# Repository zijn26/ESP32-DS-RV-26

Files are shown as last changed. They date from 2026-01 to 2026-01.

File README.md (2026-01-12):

Phần 1 . Hướng dẫn mở dự án kicad 

## 1️⃣ Giới thiệu

Project này được thiết kế bằng **KiCad** và bao gồm:

* **Schematic (sơ đồ nguyên lý)**
* **PCB Layout (mạch in nhiều lớp)**

Tài liệu này hướng dẫn cách mở và xem toàn bộ project bằng **KiCad** trên Windows, Linux hoặc macOS.

---

## 2️⃣ Phần mềm cần cài

Tải và cài đặt :

👉 **KiCad 7 hoặc KiCad 8 hoặc KiCad 9 **

Tải tại:
[https://www.kicad.org](https://www.kicad.org)

> ⚠ Khuyến nghị dùng Kicad 9, phiên bản mà project được tạo ra để tránh lỗi.

---

## 3️⃣ Cấu trúc thư mục project

Sau khi giải nén file ZIP, bạn sẽ thấy thư mục dạng:

```
MyProject/
├── esp32_module.kicad_pro
├── esp32_module.kicad_sch
├── esp32_module.kicad_pcb
├── MyFootprints.pretty
├── ul_myfootprinandsymbol
```

| File | Chức năng |
| --- | --- |
| `.kicad_pro` | File project chính  |
| `.kicad_sch` | Schematic |
| `.kicad_pcb` | PCB layout |
| `.pretty` | Footprint tùy chỉnh |
| `.kicad_sym` | Symbol tùy chỉnh |
| `ul_xxxxxxx` | File chứa các footprint và symbol tùy chỉnh |

---

## 4️⃣ Cách mở project trong KiCad

### Bước 1

Mở **KiCad**

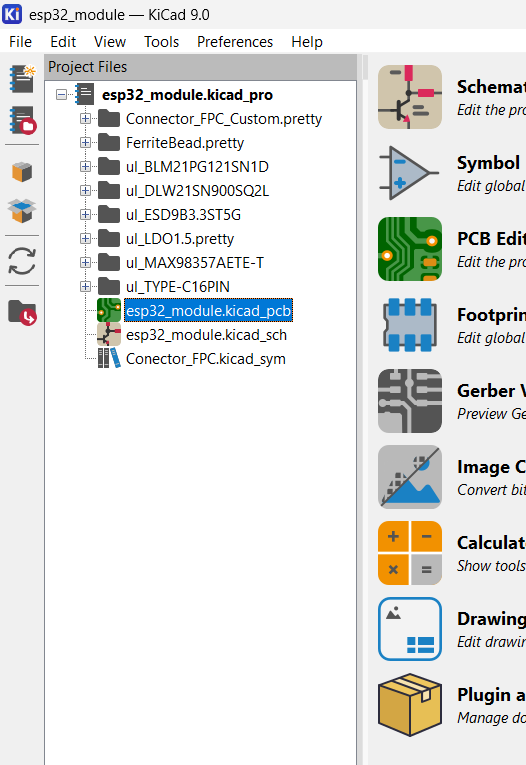
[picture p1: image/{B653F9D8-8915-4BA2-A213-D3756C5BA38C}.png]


---

### Bước 2

Nhấn **File → Open Project**

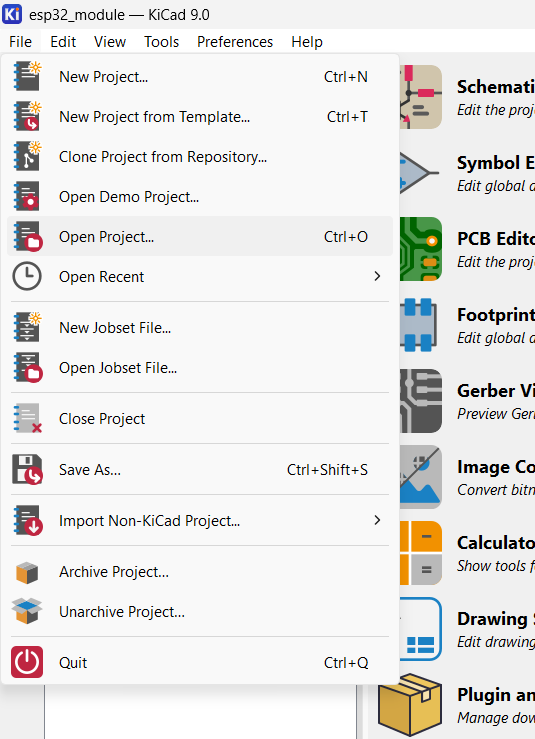
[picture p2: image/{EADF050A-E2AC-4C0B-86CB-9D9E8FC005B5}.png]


---

### Bước 3

Chọn file:

```
MyProject.kicad_pro
```

## 5️⃣ Mở Schematic (Sơ đồ nguyên lý)

Sau khi project mở:

Nhấn **Schematic Editor**

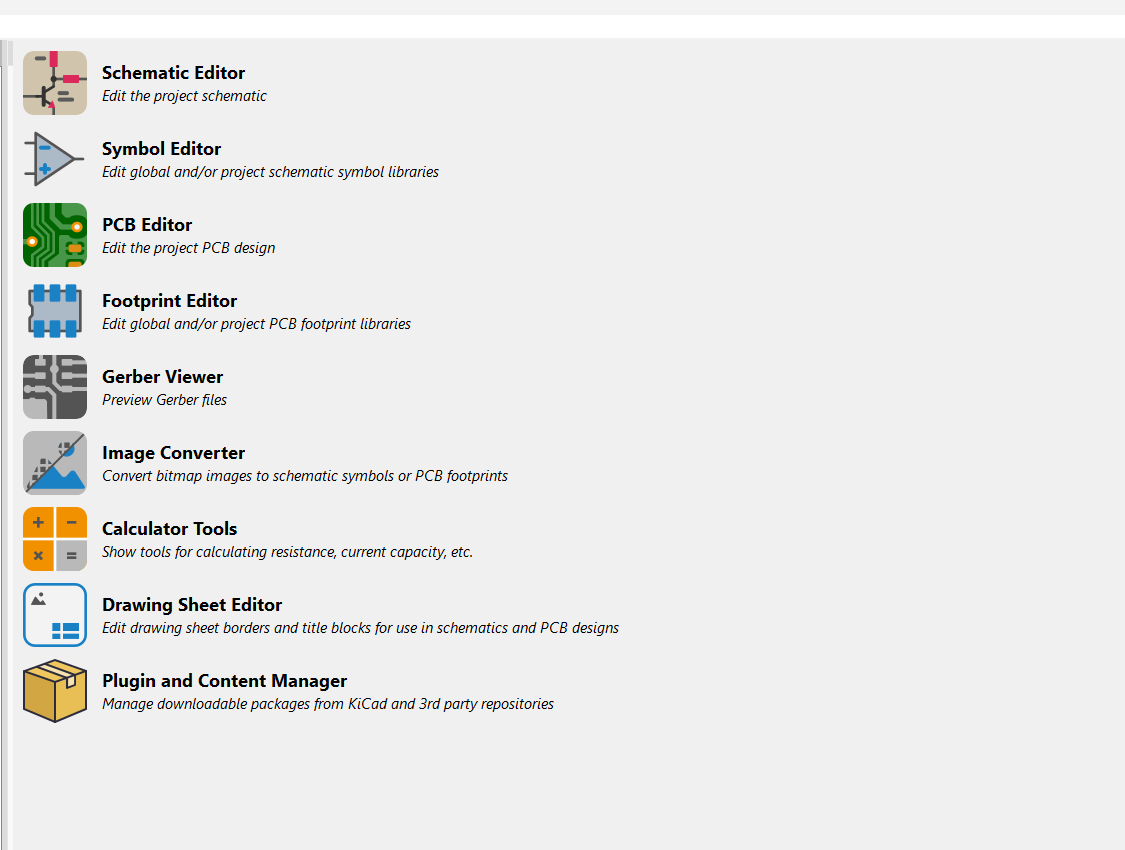
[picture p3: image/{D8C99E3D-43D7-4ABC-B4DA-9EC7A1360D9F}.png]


Sau đó sơ đồ nguyên lý sẽ xuất hiện.

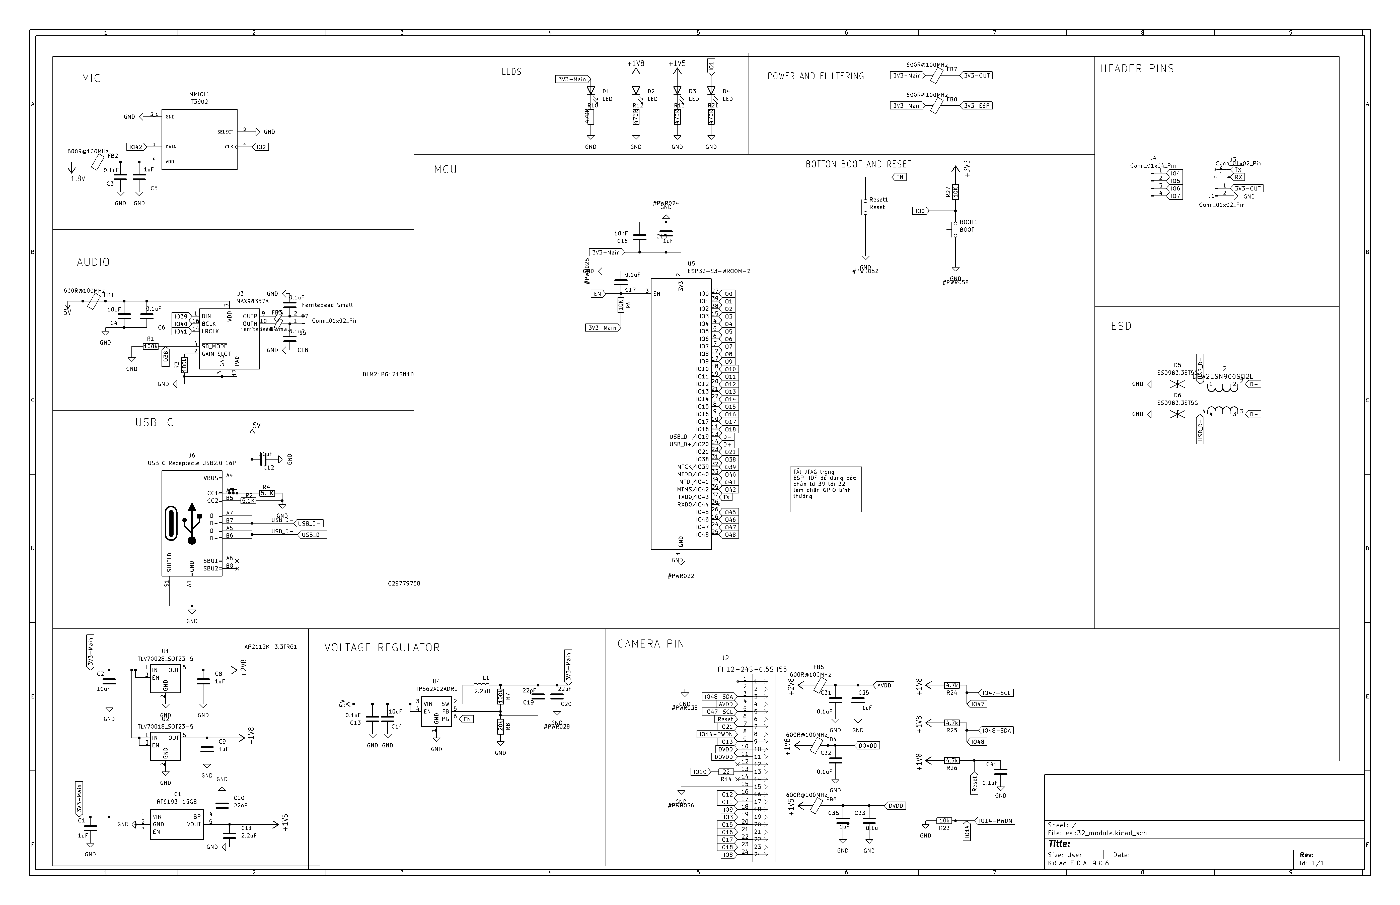
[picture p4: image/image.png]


---

## 6️⃣ Mở PCB Layout

Trong cửa sổ chính của KiCad:

Nhấn **PCB Editor**

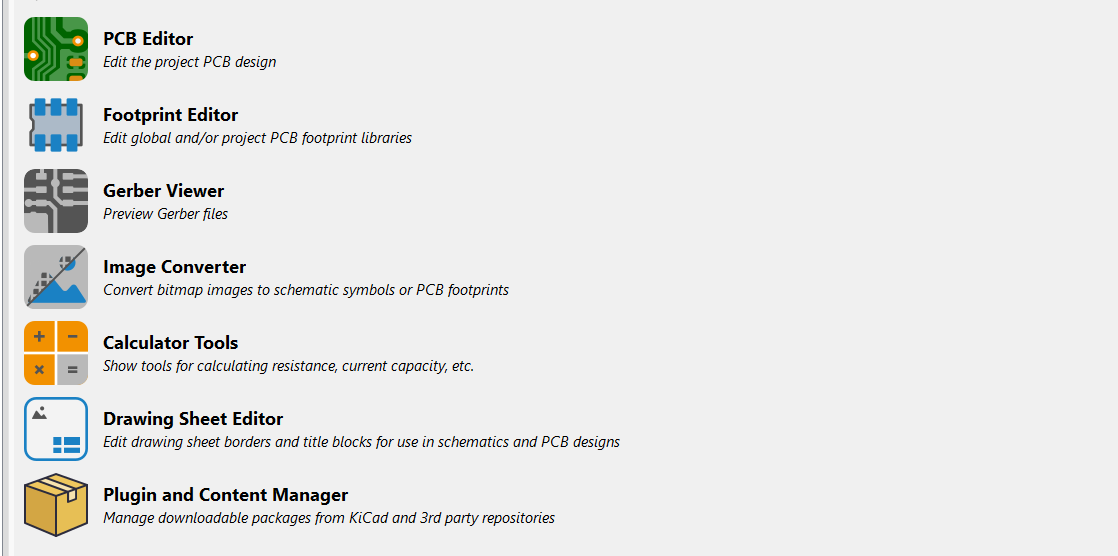
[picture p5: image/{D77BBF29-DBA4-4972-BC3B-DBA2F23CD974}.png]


PCB sẽ được mở ra với:

* Các lớp đồng (Top, Bottom, Inner layers)
* Via
* Plane
* Footprint

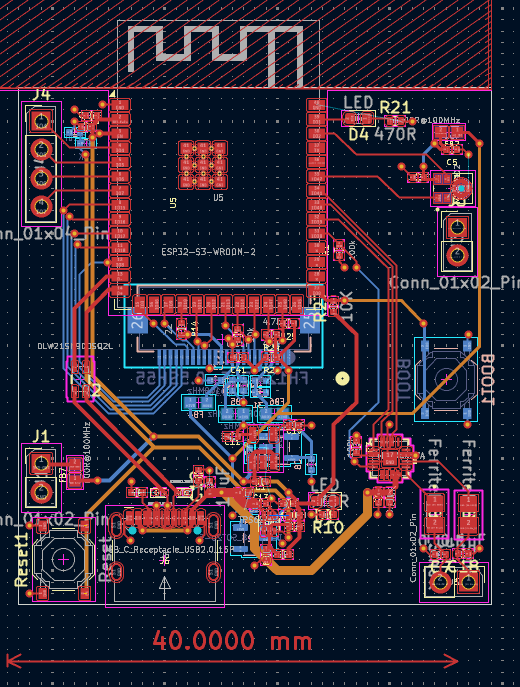
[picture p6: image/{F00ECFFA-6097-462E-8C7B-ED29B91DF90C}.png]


đang nằm **cùng thư mục với project**

Phần 2 : Thông tin về linh kiên sử dụng , giải thích về sơ đồ nguyên lý và mạch in

Thông tin về linh kiện sử dụng : 
Thầy hãy đọc file LINHKIENSUDUNG.md để biết thông tin chi tiết về linh kiện :
https://github.com/zijn26/ESP32-DS-RV-26/blob/main/LINHKIENSUDUNG.md
Thông tin về sơ đồ mạch và layout PCB , thày hãy đọc file GIAITHICH.md :
https://github.com/zijn26/ESP32-DS-RV-26/blob/main/GIAITHICH.md

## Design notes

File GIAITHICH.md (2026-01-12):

# 📋 Giải Thích Các Khối Trong Sơ Đồ Schematic và PCB Layout

---

## 🏗️ Tổng Quan Cấu Trúc PCB 4 Lớp

| Lớp | Tên | Chức năng |
|-----|-----|---|
| **Lớp 1** | Top | Lắp các linh kiện chính: Module ESP32-S3, Antenna, Mic, USB-C, ... |
| **Lớp 2** | GND Plane | Đổ full đồng làm mặt phẳng GND |
| **Lớp 3** | Power/Signal | Đi các đường nguồn (3V3, 5V, 1V8, 1V5) và tín hiệu (EN, ...) |
| **Lớp 4** | Bottom | Linh kiện phụ và linh kiện lớn: FPC Connector, LDO 2V8, LDO 1V8 |

---

## 1. 🔌 Khối USB-C (Nạp Code & Cấp Nguồn)

### Schematic

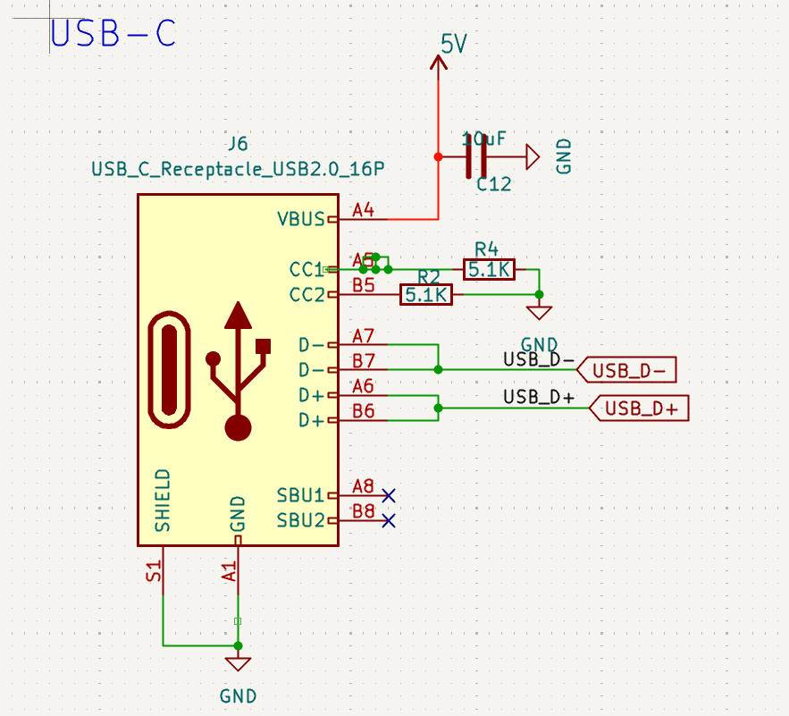
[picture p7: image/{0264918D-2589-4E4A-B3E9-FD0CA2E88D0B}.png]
USB-C Schematic


### Mô tả

Em sử dụng **USB-C 16P** với các kết nối:

- **Chân CC1 và CC2**: Dùng 2 điện trở **5.1kΩ** kéo xuống GND
- **Chân SHIELD**: Nối thẳng xuống GND

### Layout

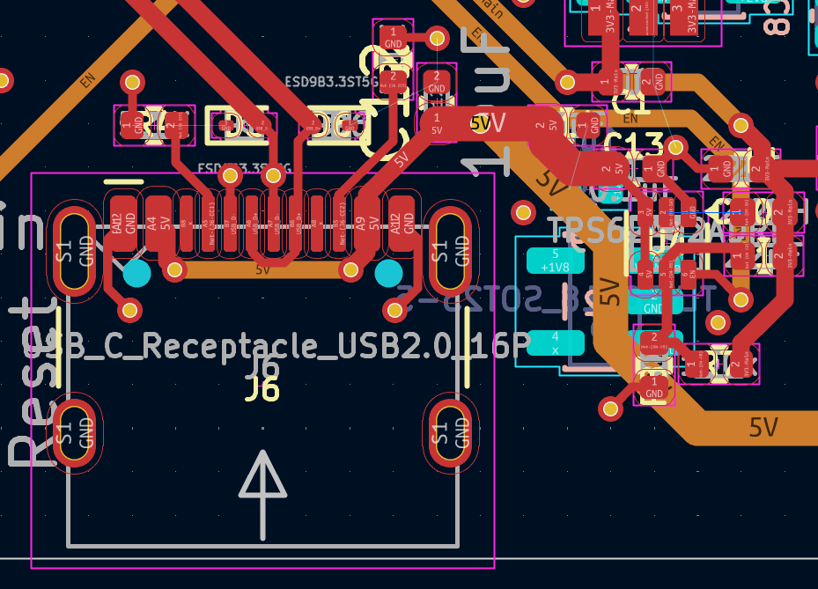
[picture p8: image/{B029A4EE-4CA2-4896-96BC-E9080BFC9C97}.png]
USB-C Layout


#### Chi tiết thiết kế:

- Nối 2 chân **B7** và **A7** lại với nhau thông qua **via Through**
- Dây **D-** và **D+** đi qua:
  1. **ESD9B3.3ST5G** (ESD Protection Diode)
  2. **DLW21SN900SQ2L** (Common Mode Choke) để lọc nhiễu
  3. Cuối cùng đi tới ESP32-S3

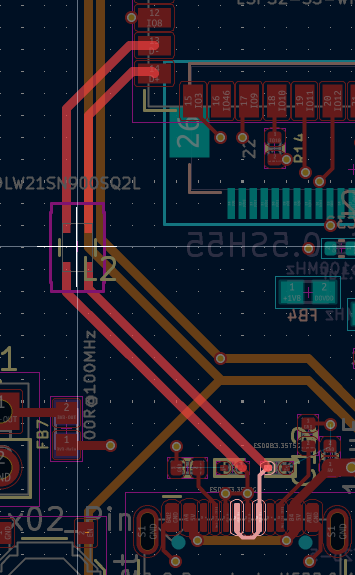
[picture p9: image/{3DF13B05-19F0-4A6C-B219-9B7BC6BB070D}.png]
USB Data Lines


- 2 pad **5V** được nối lại với nhau thông qua via through, đi qua tụ bulk **10µF (C12)** trước khi đi tới khối Buck

> **❓ Câu hỏi:**
> 1. Cách nối B7, A7 lại với nhau thông qua via Through có đúng không ạ ?
> 2. Cách dùng ESD protection diode ESD9B3.3ST5G có đúng không ạ ?
> 3. Cách đi dây đã ổn chưa ạ ?

---

## 2. ⚡ Khối Buck Converter (5V → 3V3)

### Schematic & Layout

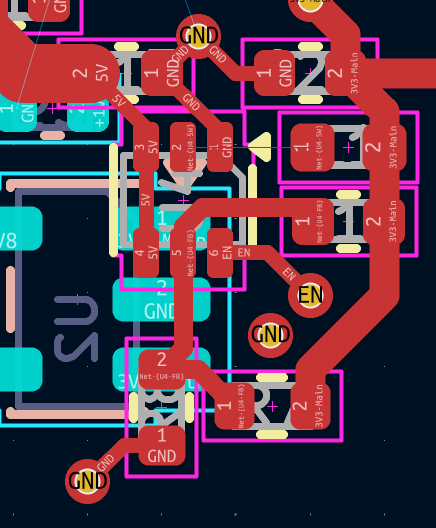
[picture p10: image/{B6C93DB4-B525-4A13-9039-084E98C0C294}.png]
Buck Schematic

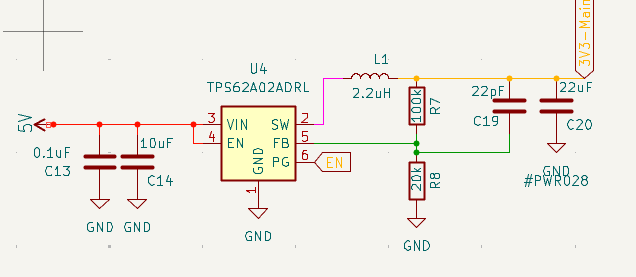
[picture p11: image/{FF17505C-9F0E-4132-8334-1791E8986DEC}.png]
Buck Layout


### Mô tả

- Sử dụng **2 tụ decoupling** ngay sát chân 5V để đón dòng vào Buck
- Đầu ra sử dụng **mạch chia áp** để nhận được 3V3

### LDO 1V8 (Lớp 4 - Bottom)

Ở bên dưới Buck (lớp 4), đặt **LDO 1V8** để:
- Đón dòng 3V3 và chuyển thành 1V8
- Cấp nguồn cho chân **DOVDD** của FPC Connector

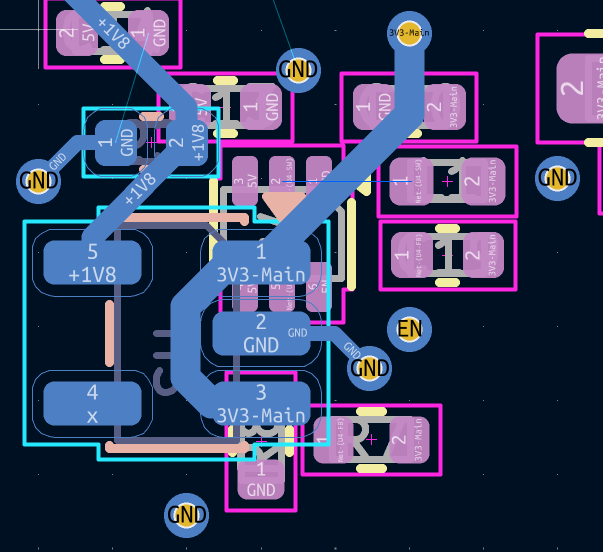
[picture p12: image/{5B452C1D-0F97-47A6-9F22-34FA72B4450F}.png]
LDO 1V8 - 1

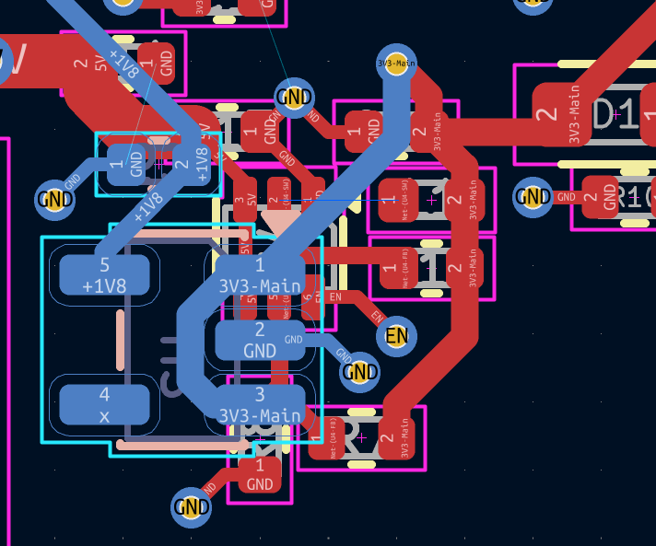
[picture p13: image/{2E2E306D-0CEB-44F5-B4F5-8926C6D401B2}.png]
LDO 1V8 - 2

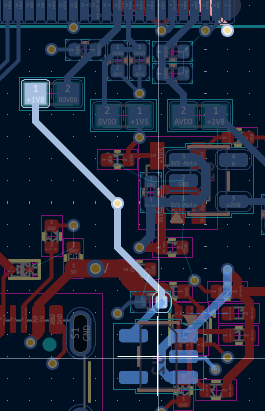
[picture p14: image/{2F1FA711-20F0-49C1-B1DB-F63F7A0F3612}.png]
LDO 1V8 - 3


### Điều khiển Power Good (PG)

Sử dụng chân **PG** của Buck để điều khiển chân **EN** của ESP32-S3:
- Mục đích: Khi dòng 3V3 ổn định thì module mới khởi động

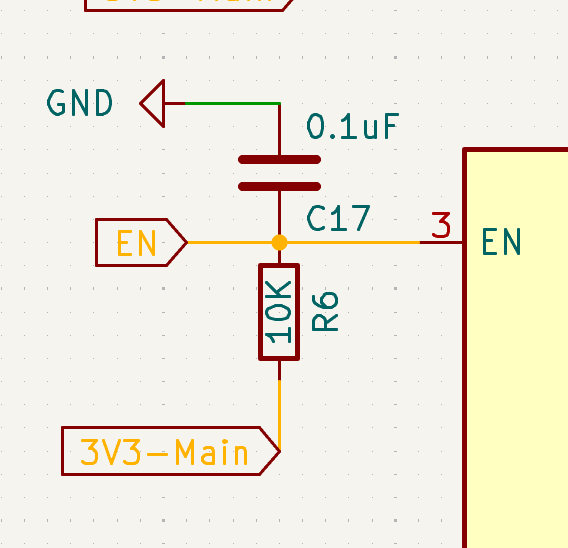
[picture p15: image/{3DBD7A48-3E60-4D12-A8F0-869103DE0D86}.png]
PG Control - 1

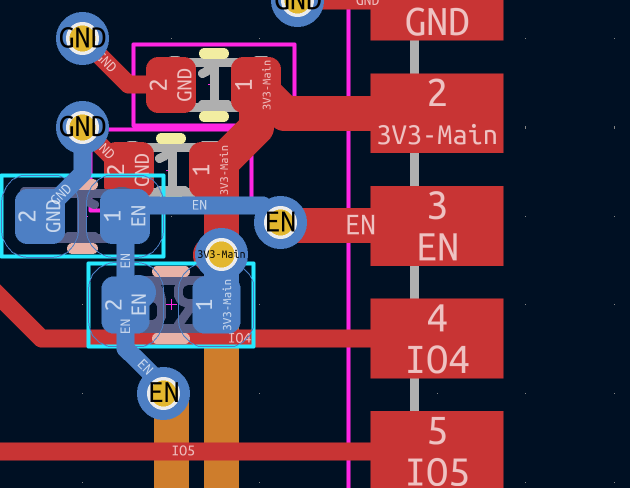
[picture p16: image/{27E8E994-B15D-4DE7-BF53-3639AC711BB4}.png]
PG Control - 2


> *Mạch màu xanh: Chân PG kết nối vào chân EN của ESP32 để khởi động*

### Cấp nguồn cho ESP32-S3

- Cấp nguồn **3V3** từ Buck
- Sử dụng **2 tụ decoupling** sát chân 3V3 của module

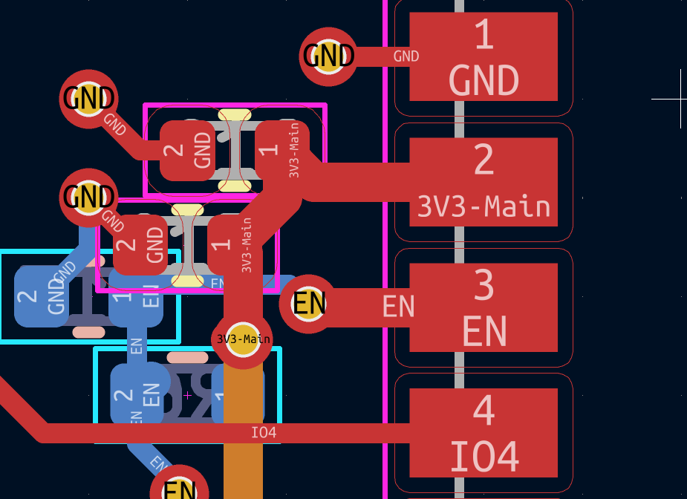
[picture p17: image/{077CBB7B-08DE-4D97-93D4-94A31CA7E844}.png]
ESP32 Power


---

## 3. 🔋 Khối LDO

### Bố trí

| LDO | Vị trí | Chức năng |
|-----|---|---|
| **3V3 → 1V5** | Lớp 1 (Top) | Cấp nguồn DVDD cho Camera |
| **3V3 → 2V8** | Lớp 4 (Bottom) | Cấp nguồn AVDD cho Camera |

> Cả 2 khối LDO được đặt **gần FPC Connector** để giảm độ dài đường dây nguồn.

### Schematic & Layout

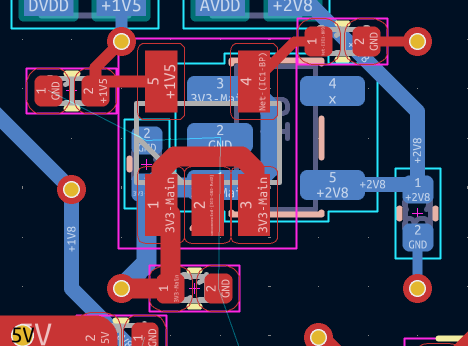
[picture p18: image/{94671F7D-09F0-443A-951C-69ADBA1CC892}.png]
LDO Overview

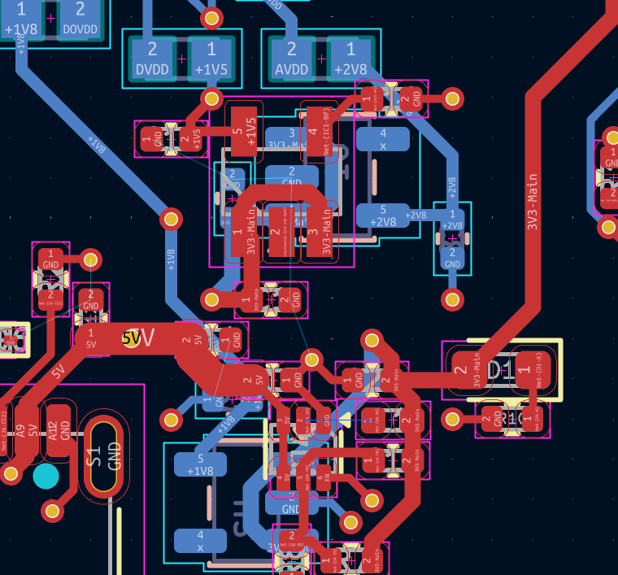
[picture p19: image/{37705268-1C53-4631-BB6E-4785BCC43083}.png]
LDO Layout 1

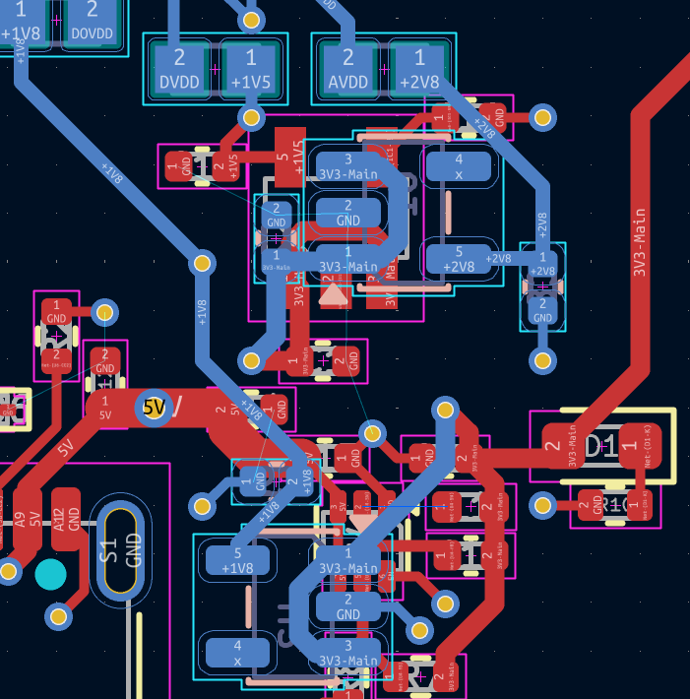
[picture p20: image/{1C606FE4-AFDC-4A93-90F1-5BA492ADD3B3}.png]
LDO Layout 2

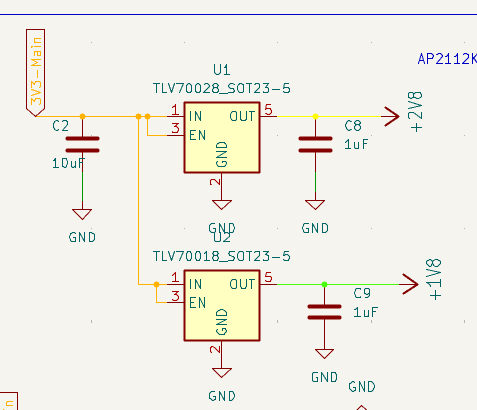
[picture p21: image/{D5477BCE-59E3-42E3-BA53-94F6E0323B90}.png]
LDO Layout 3

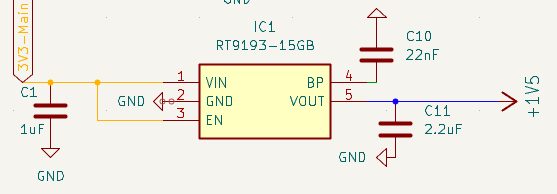
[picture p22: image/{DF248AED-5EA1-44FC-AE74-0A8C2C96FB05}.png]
LDO Layout 4


---

## 4. 📷 Khối FPC Connector (Camera)

### Schematic

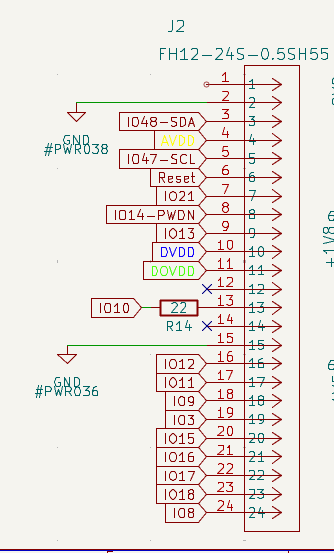
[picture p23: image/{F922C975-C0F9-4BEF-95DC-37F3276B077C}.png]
FPC Schematic 1

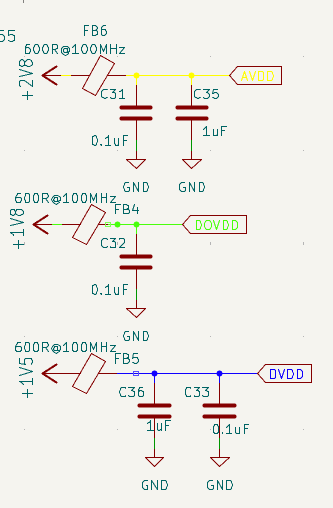
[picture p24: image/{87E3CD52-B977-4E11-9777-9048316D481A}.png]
FPC Schematic 2

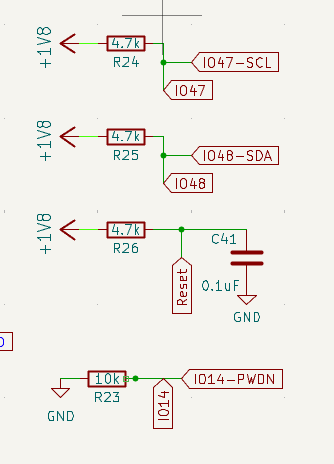
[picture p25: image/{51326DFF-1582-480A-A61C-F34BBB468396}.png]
FPC Schematic 3


### Mô tả

Khối FPC Connector kết nối **camera OV2640** với ESP32-S3:
- Đặt **gần ESP32-S3** để giảm nhiễu và giảm độ dài dây kết nối

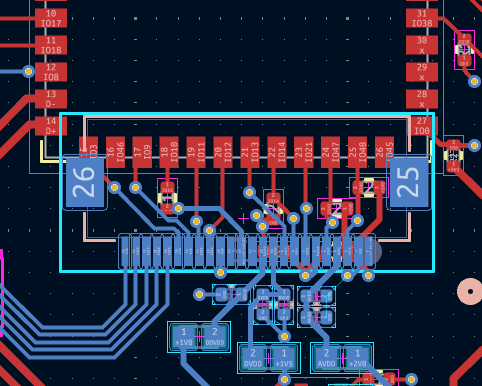
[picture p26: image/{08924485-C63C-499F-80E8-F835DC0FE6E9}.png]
FPC Layout


### Thiết kế chi tiết

| Thành phần | Thiết kế |
|---|---|
| **Ferrite Bead** | Giảm nhiễu cho các chân nguồn của FPC |
| **AVDD (2V8)** | Ferrite Bead BEADC1608X95N 600R@100MHz + 2 tụ decoupling (0.1µF, 1µF) |
| **DOVDD (1V8)** | Tương tự AVDD |
| **DVDD (1V5)** | Tương tự AVDD |
| **MCLK** | GPIO 10 của ESP32-S3 cấp clock |
| **SDA/SCL** | Mạch pull-up kết hợp GPIO 47, GPIO 48 |
| **RESET** | Mạch RC để reset sạch, ổn định |
| **PWDN** | Mạch pull-down |

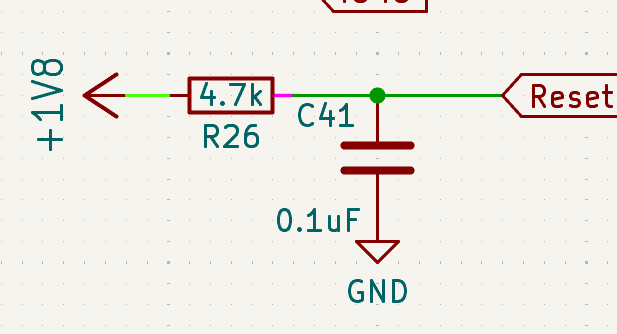
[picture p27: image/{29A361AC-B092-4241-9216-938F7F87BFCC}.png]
Reset Circuit

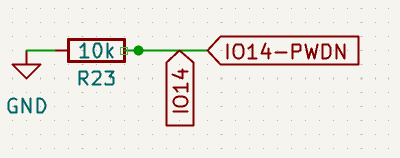
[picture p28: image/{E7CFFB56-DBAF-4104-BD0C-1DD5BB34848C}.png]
PWDN Circuit


---

## 5. 🔊 Khối Audio Amplifier (AMP)

### Bố trí

- Đặt **gần mép board**, cách xa LDO và FPC để tránh nhiễu
- 3 dây **DIN, BCLK, LRCLK** đi song song, thẳng

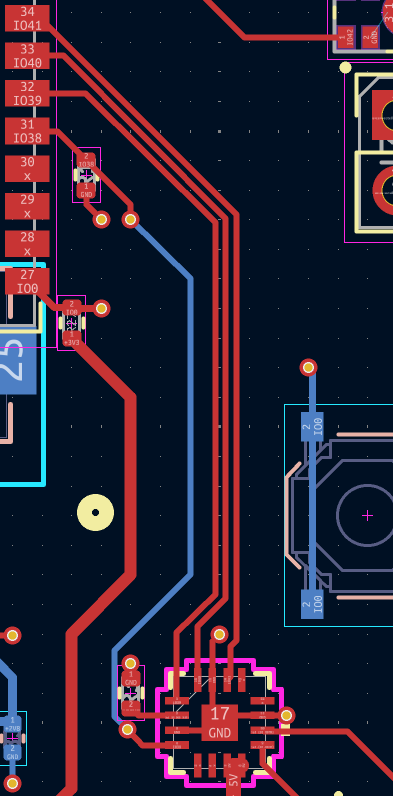
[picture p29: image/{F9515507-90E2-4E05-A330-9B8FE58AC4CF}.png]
AMP Layout


### Thiết kế chi tiết

| Chân | Thiết kế |
|---|---|
| **SD_MODE** | Mạch pull-down + GPIO38 điều khiển |
| **VDD** | Ferrite Bead giảm nhiễu + 2 tụ decoupling |
| **OUTP/OUTN** | 2 tụ trên đường dây tín hiệu xuất ra → Header Pin → Loa |

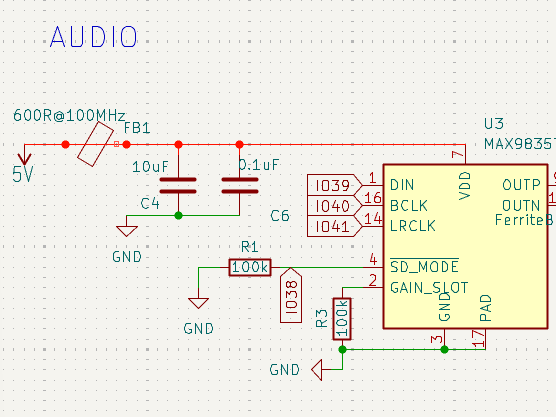
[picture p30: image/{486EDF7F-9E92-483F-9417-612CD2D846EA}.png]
AMP VDD

AMP Schematic
AMP Output

> ⚠️ *Em đã sửa lại mạch: Xóa các Ferrite Bead sau chân OUTP/OUTN, chỉ dùng tụ*

AMP Output Updated

> **❓ Câu hỏi:**
> Với các chân OUTP và OUTN nếu chỉ dùng tụ không thì âm thanh đầu ra có bị dè hay nhiễu không? Nếu có thì em nên khắc phục như thế nào?

---

## 6. 🎤 Khối Mic PDM

### Bố trí

- Đặt **tránh xa LDO, Buck, FPC Connector và AMP** để tránh nhiễu
- Đặt **gần ESP32-S3** để dây DATA và CLK đi ngắn nhất, thẳng nhất

### Thiết kế chi tiết

| Chân | Thiết kế |
|---|---|
| **VDD** | Ferrite Bead giảm nhiễu + 2 tụ decoupling |
| **SELECT** | Nối thẳng xuống GND |
| **Nguồn** | Cấp 1V8 cho Mic |

Mic Schematic
Mic Layout
Mic SELECT
Mic Power

---

## 7. 📐 Tổng Quan Layout PCB

### Lớp Top (Lớp 1)

PCB Top

### Lớp Bottom (Lớp 4)

PCB Bottom

### Các thành phần khác

| Thành phần | Layout |
|---|---|
| **Nút Reset** | Reset Button |
| **Nút Boot** | Boot Button |

### Routing dây Data FPC

FPC Data Lines

> **Lưu ý:** Các dây data của FPC đi ở **Lớp 4**, còn 2 dây D- và D+ đi ở **Lớp 1**

### Hình ảnh tổng quan

Full PCB

---

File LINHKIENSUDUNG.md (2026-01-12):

# 📒 Danh Sách & Thông Tin Linh Kiện

---

## 🧩 1. Giới Thiệu

Tài liệu này mô tả **toàn bộ các linh kiện** được sử dụng trong project PCB, bao gồm:

- Tên linh kiện & chức năng
- Thông số kỹ thuật chi tiết
- Hình ảnh minh họa
- Link tham khảo trên JLCPCB

---

## 📋 2. Danh Sách Linh Kiện Tổng Quan

| STT | Tên Linh Kiện | Mã JLCPCB |
|:---:|---|---|
| 1 | ESP32-S3-WROOM Module N16R8 | C2913202 |
| 2 | FPC Connector 24-pin (Camera) | C202112 |
| 3 | Buck Converter TPS62A02 | C5820994 |
| 4 | LDO TLV70028 (2.8V) | C5820994 |
| 5 | LDO RT9193-15GB (1.5V) | C2972229 |
| 6 | PDM Microphone MMICT390200012 | C3171752 |
| 7 | Audio Amplifier MAX98357AETE+T | C910544 |
| 8 | ESD Protection ESD9B3.3ST5G | C96512 |
| 9 | Common Mode Choke DLW21SN900SQ2L | C97856 |
| 10 | USB Type-C 16P | C393939 |

---

## 🧰 3. Chi Tiết Linh Kiện

---

### 🧠 1. ESP32-S3-WROOM Module

| Thông số | Giá trị |
|---|---|
| **Chức năng** | Vi điều khiển chính, Wi-Fi, Bluetooth, xử lý camera, audio |
| **Điện áp** | 3.3V |
| **CPU** | Xtensa dual-core 32-bit LX7 @ 240 MHz |
| **SRAM** | 512 kB nội bộ |
| **Flash** | 16 MB (SPI) |
| **PSRAM** | 8 MB ngoài |
| **GPIO** | 45 chân đa năng (ADC, SPI, I2C, UART, PWM, USB OTG) |

ESP32-S3 Module

🔗 **Link JLCPCB:** [C2913202](https://jlcpcb.com/partdetail/3198300-ESP32_S3_WROOM_1N16R8/C2913202)

---

### 📷 2. FPC Connector 24-pin (Camera)

| Thông số | Giá trị |
|---|---|
| **Chức năng** | Kết nối camera OV2640 / OV5640 / OV3660 |
| **Pitch** | 0.5mm |
| **Tương thích** | OV2640 (2MP), OV5640 (5MP), OV3660 (3MP) |

FPC Connector - 1
FPC Connector - 2

#### Các chân chính:

| Chân | Chức năng |
|---|---|
| XCLK | Clock |
| PCLK | Pixel clock |
| HREF | Horizontal reference |
| VSYNC | Vertical sync |
| D0-D7 | Data bits |
| SDA/SCL | I2C config |

🔗 **Link JLCPCB:** [C202112](https://jlcpcb.com/partdetail/HRS_Hirose-FH12_24S_0_5SH_55/C202112)

---

### ⚡ 3. Buck Converter TPS62A02

| Thông số | Giá trị |
|---|---|
| **Chức năng** | Hạ áp 5V → 3.3V cho toàn hệ thống |
| **Điện áp vào** | 2.5V - 5.5V |
| **Điện áp ra** | 0.6V - VIN (điều chỉnh được) |
| **Dòng tối đa** | 2A |
| **Tần số chuyển mạch** | 2.4MHz |
| **Quiescent current** | < 23µA |
| **Package** | SOT-563 (DRL-6) |

Buck TPS62A02 - 1
Buck TPS62A02 - 2

#### Tính năng bảo vệ:

- ✅ Soft-start tích hợp
- ✅ Bảo vệ ngắn mạch (HICCUP mode)
- ✅ Xả output chủ động
- ✅ Thermal shutdown
- ✅ Độ chính xác feedback 1% (0-125°C)
- ✅ Hỗ trợ 100% duty cycle cho dropout thấp

🔗 **Link JLCPCB:** [C5820994](https://jlcpcb.com/parts/componentSearch?searchTxt=C5820994)

---

### 🔋 4. LDO TLV70028 (2.8V)

| Thông số | Giá trị |
|---|---|
| **Chức năng** | LDO 200mA, đầu ra cố định 2.8V cho Camera |
| **Điện áp vào** | 2V - 5.5V |
| **Dropout** | 30mV @ 200mA |
| **Quiescent current** | ~3.9µA |
| **PSRR** | 70dB @ 10kHz |
| **Package** | SOT-23-5 (DBV) |
| **Kích thước** | 2.9 x 1.6mm |

LDO TLV70028 - 1
LDO TLV70028 - 2

#### Pinout:

| Pin | Chức năng |
|-----|---|
| 1 | IN |
| 2 | GND |
| 3 | EN |
| 4 | NC |
| 5 | OUT |

> **Ứng dụng:** LDO hậu Buck TPS62A02 cho rail 2.8V ổn định, cấp nguồn AVDD cho Camera (dòng < 200mA)

🔗 **Link JLCPCB:** [C5820994](https://jlcpcb.com/partdetail/TexasInstruments-TPS62A02ADRLR/C5820994)

---

### 🔋 5. LDO RT9193-15GB (1.5V)

| Thông số | Giá trị |
|---|---|
| **Chức năng** | LDO 300mA, đầu ra cố định 1.5V cho Camera |
| **Điện áp vào** | 2.5V - 5.5V |
| **Dropout** | 220mV @ 300mA |
| **Quiescent current** | 90-130µA |
| **PSRR** | 70dB (100Hz) - 50dB (10kHz) |
| **Noise** | < 100µVRMS |
| **Package** | SOT-23-5 (GB/Z00) |

LDO RT9193 - 1
LDO RT9193 - 2
LDO RT9193 - 3

#### Pinout:

| Pin | Chức năng |
|-----|---|
| 1 | IN |
| 2 | GND |
| 3 | EN/SHDN |
| 4 | BYP (noise reduction) |
| 5 | OUT |

#### Tính năng:

- ✅ Current limit tích hợp
- ✅ Thermal shutdown (165°C)
- ✅ Shutdown current < 0.01µA
- ✅ Start-up nhanh < 50µs
- ✅ Chỉ cần C_OUT 1µF

> **Ứng dụng:** LDO hậu Buck TPS62A02 cho rail 1.5V ổn định, cấp nguồn DVDD cho Camera

🔗 **Link JLCPCB:** [C2972229](https://jlcpcb.com/partdetail/RichtekTech-RT919315GB/C2972229)

---

### 🎤 6. PDM Microphone MMICT390200012

| Thông số | Giá trị |
|---|---|
| **Chức năng** | Thu âm thanh dạng PDM |
| **Điện áp** | 1.65V - 3.63V |
| **Dòng tiêu thụ** | 650µA |
| **Độ nhạy** | -32dB ±1dB @ 94dB SPL |
| **SNR** | 64dB |
| **SPL tối đa** | 120dB |
| **Tần số** | 36Hz - 20kHz |
| **Hướng thu** | Omnidirectional, bottom port |
| **EIN** | 30dBA (low noise) |

PDM Mic - 1
PDM Mic - 2

#### Package:

| Thông số | Giá trị |
|---|---|
| Kích thước | 3.50 x 2.65 x 0.98mm |
| Lắp đặt | Surface mount, 5 chân |
| Nhiệt độ | -40°C đến 85°C |
| Chuẩn | RoHS compliant |

> **Ứng dụng:** Interface PDM tích hợp với ESP32-S3 I2S/PDM RX cho voice recognition hoặc audio streaming kết hợp camera OV2640

🔗 **Link JLCPCB:** [C3171752](https://jlcpcb.com/partdetail/TDKInvenSense-MMICT390200012/C3171752)

---

### ⚡ 7. ESD Protection Diode ESD9B3.3ST5G

| Thông số | Giá trị |
|---|---|
| **Chức năng** | Bảo vệ ESD hai chiều cho đường tín hiệu 3.3V |
| **Breakdown voltage** | 7V max |
| **Clamping voltage** | 11.5V |
| **Capacitance** | 15pF @ 1MHz |
| **Công suất** | 0.3W |
| **Leakage current** | < 50nA |
| **Nhiệt độ** | -55°C đến +150°C (TJ) |
| **Package** | SOD-923 (0.8 x 0.6 x 0.37mm) |

ESD Diode - 1
ESD Diode - 2

#### Ứng dụng:

- USB-C16PIN (VBUS, D+, D-, CC)
- GPIO ESP32-S3
- I2S audio lines

> **Lắp đặt:** Đặt parallel với đường tín hiệu cần bảo vệ. Không cần hướng pin cụ thể (bidirectional).

🔗 **Link JLCPCB:** [C96512](https://jlcpcb.com/partdetail/onsemi-ESD9B33ST5G/C96512)

---

### � 8. Common Mode Choke DLW21SN900SQ2L

| Thông số | Giá trị |
|---|---|
| **Chức năng** | Bộ lọc nhiễu chế độ chung (Common Mode Filter) |
| **Trở kháng** | 90Ω @ 100MHz (±25%) |
| **Dòng định mức** | 330mA |
| **Điện áp định mức** | 50V DC (chịu được 125V) |
| **Điện trở DC** | max 0.35Ω mỗi đường |
| **Cách điện** | min 10MΩ |
| **Package** | SMD 0805 (2.0 x 1.2 x 1.2mm) |

CMC - 1
CMC - 2

#### Cấu trúc:

- 4 chân SMD (2 line pairs)
- Cấu hình 1 mạch (line 1-2 và line 3-4)
- High coupling coefficient giữ tín hiệu differential nguyên vẹn

> **Ứng dụng:** USB, I2S, high-speed data lines

🔗 **Link JLCPCB:** [C97856](https://jlcpcb.com/partdetail/MurataElectronics-DLW21SN900SQ2L/C97856)

---

### 🔊 9. Audio Amplifier MAX98357AETE+T

| Thông số | Giá trị |
|---|---|
| **Chức năng** | Khuếch đại âm thanh Class D cho loa |
| **Điện áp** | 2.5V - 5.5V |
| **Công suất** | 3.2W @ 4Ω/5V (THD+N 10%) |
| **Hiệu suất** | 92% |
| **Noise floor** | 22.8μVRMS |
| **THD+N** | 0.013% @ 1kHz/1W |
| **PSRR** | 77dB @ 1kHz |
| **Quiescent** | 2.4mA |
| **Sample rate** | 8-96kHz |
| **Package** | TQFN-16 (3x3mm) |

Audio AMP

#### Tính năng:

- ✅ Không cần MCLK
- ✅ Gain có thể chọn: 6/12/15dB
- ✅ Filterless output (giảm EMI)
- ✅ Shielded GND riêng cho output stage

#### Pinout chính:

| Chân | Chức năng |
|---|---|
| VDD/GND | Nguồn |
| BCLK/LRCLK/DIN | I2S input |
| GAIN_SLOT | Chọn gain |
| OUTP/OUTN | Speaker differential output |
| SD | Shutdown control |

> **Ứng dụng:** Tối ưu cho ESP32-S3 với I2S output

🔗 **Link JLCPCB:** [C910544](https://jlcpcb.com/partdetail/978950-MAX98357AETET/C910544)

---

### 🔌 10. USB Type-C 16P

| Thông số | Giá trị |
|---|---|
| **Chức năng** | Cấp nguồn + giao tiếp USB |
| **Điện áp định mức** | 30V |
| **Dòng tối đa** | 3A mỗi chân |
| **Nhiệt độ hoạt động** | -40°C đến +85°C |
| **Độ bền** | 10,000 chu kỳ cắm/rút |
| **Kháng trở tiếp xúc** | ≤ 20mΩ |
| **Cách điện** | > 100MΩ |
| **Lắp ráp** | Surface mount, right angle |

USB-C - 1
USB-C - 2

#### Kích thước:

| Thông số | Giá trị |
|---|---|
| Kích thước | ~8.94 x 7.35 x 3.16mm |
| Kiểu | Horizontal SMD |
| Pitch | Tiêu chuẩn Type-C |
| Solder heat resistance | 260°C/3s |

> **Lưu ý:** Tích hợp positioning peg giảm misalignment khi reflow. Đạt chuẩn RoHS.

🔗 **Link JLCPCB:** [C393939](https://jlcpcb.com/partdetail/SHOUHAN-TYPEC16PIN/C393939)

---

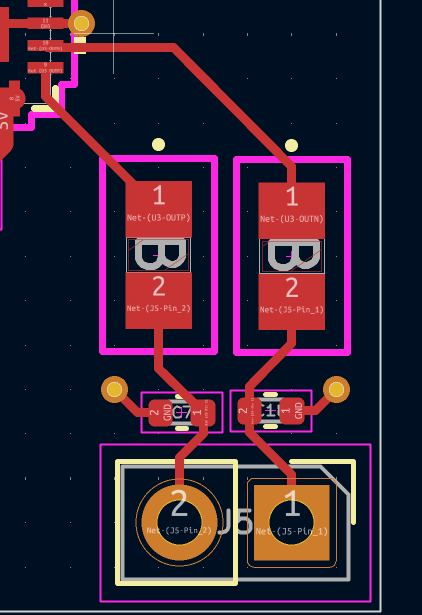
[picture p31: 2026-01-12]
image/{BC1A247C-B683-4670-9397-5359815A4F0C}.png

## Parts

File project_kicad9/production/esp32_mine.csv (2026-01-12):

Reference | Qty | Value | DNP | Footprint | Datasheet | MNF PART NUMBER | Description | LCSC
BOOT1 | 1 | BOOT |  | Button_Switch_SMD:SW_Push_1P1T_XKB_TS-1187A | ~ | C318884 | Push button switch, generic, two pins | C318884
C1 | 1 | 1uF |  | Capacitor_SMD:C_0402_1005Metric | ~ | C52923 |  | C52923
C2 | 1 | 10uF |  | Capacitor_SMD:C_0402_1005Metric | ~ | C15525 |  | C15525
C3 | 1 | 0.1uF |  | Capacitor_SMD:C_0402_1005Metric | ~ | C1525 |  | C1525
C4 | 1 | 10uF |  | Capacitor_SMD:C_0402_1005Metric | ~ | C1525 |  | C1525
C5 | 1 | 1uF |  | Capacitor_SMD:C_0402_1005Metric | ~ | C15525 |  | C15525
C6 | 1 | 0.1uF |  | Capacitor_SMD:C_0402_1005Metric | ~ | C15525 |  | C15525
C7 | 1 | 0.1uF |  | Capacitor_SMD:C_0402_1005Metric | ~ | C15525 |  | C15525
C8 | 1 | 1uF |  | Capacitor_SMD:C_0402_1005Metric | ~ | C52923 |  | C52923
C9 | 1 | 1uF |  | Capacitor_SMD:C_0402_1005Metric | ~ | C52923 |  | C52923
C10 | 1 | 22nF |  | Capacitor_SMD:C_0402_1005Metric | ~ | C15525 |  | C15525
C11 | 1 | 2.2uF |  | Capacitor_SMD:C_0402_1005Metric | ~ | C107369 |  | C107369
C12 | 1 | 10uF |  | Capacitor_SMD:C_0402_1005Metric | ~ | C15525 |  | C15525
C13 | 1 | 0.1uF |  | Capacitor_SMD:C_0402_1005Metric | ~ | C1525 |  | C1525
C14 | 1 | 10uF |  | Capacitor_SMD:C_0402_1005Metric | ~ | C15525 |  | C15525
C15 | 1 | 1uF |  | Capacitor_SMD:C_0402_1005Metric | ~ | C52923 |  | C52923
C16 | 1 | 10nF |  | Capacitor_SMD:C_0402_1005Metric | ~ | C15195 |  | C15195
C17 | 1 | 0.1uF |  | Capacitor_SMD:C_0402_1005Metric | ~ | C1525 |  | C1525
C18 | 1 | 0.1uF |  | Capacitor_SMD:C_0402_1005Metric | ~ | C15525 |  | C15525
C19 | 1 | 22pF |  | Capacitor_SMD:C_0402_1005Metric | ~ | C70464 |  | C70464
C20 | 1 | 22uF |  | Capacitor_SMD:C_0402_1005Metric | ~ | C105226 |  | C105226
C31 | 1 | 0.1uF |  | Capacitor_SMD:C_0402_1005Metric | ~ | C1525 |  | C1525
C32 | 1 | 0.1uF |  | Capacitor_SMD:C_0402_1005Metric | ~ | C1525 |  | C1525
C33 | 1 | 0.1uF |  | Capacitor_SMD:C_0402_1005Metric | ~ | C1525 |  | C1525
C35 | 1 | 1uF |  | Capacitor_SMD:C_0402_1005Metric | ~ | C52923 |  | C52923
C36 | 1 | 1uF |  | Capacitor_SMD:C_0402_1005Metric | ~ | C52923 |  | C52923
C41 | 1 | 0.1uF |  | Capacitor_SMD:C_0402_1005Metric | ~ | C1525 |  | C1525
D1 | 1 | LED |  | LED_SMD:LED_0603_1608Metric | ~ | C2286 |  | C2286
D2 | 1 | LED |  | LED_SMD:LED_0603_1608Metric | ~ | C2286 |  | C2286
D3 | 1 | LED |  | LED_SMD:LED_0603_1608Metric | ~ | C2286 |  | C2286
D4 | 1 | LED |  | LED_SMD:LED_0603_1608Metric | ~ | C2286 |  | C2286
D5 | 1 | ESD9B3.3ST5G |  | Diode_SMD:D_SOD-923 | https://www.onsemi.com/pub/Collateral/ESD9B-D.PDF |  | ESD protection diode, 3.3Vrwm, SOD-923
D6 | 1 | ESD9B3.3ST5G |  | Diode_SMD:D_SOD-923 | https://www.onsemi.com/pub/Collateral/ESD9B-D.PDF |  | ESD protection diode, 3.3Vrwm, SOD-923
FB1 | 1 | 600R@100MHz |  | FerriteBead:BEADC1608X95N | ~ | C19330 | Ferrite bead
FB2 | 1 | 600R@100MHz |  | FerriteBead:BEADC1608X95N | ~ | C19330 | Ferrite bead
FB3 | 1 | FerriteBead_Small |  | FerriteBead:ul_BLM21PG121SN1D | ~ |  | Ferrite bead, small symbol
FB4 | 1 | 600R@100MHz |  | FerriteBead:BEADC1608X95N | ~ | C19330 | Ferrite bead
FB5 | 1 | 600R@100MHz |  | FerriteBead:BEADC1608X95N | ~ | C19330 | Ferrite bead
FB6 | 1 | 600R@100MHz |  | FerriteBead:BEADC1608X95N | ~ | C19330 | Ferrite bead
FB7 | 1 | 600R@100MHz |  | FerriteBead:BEADC1608X95N | ~ | C19330 | Ferrite bead
FB8 | 1 | 600R@100MHz |  | FerriteBead:BEADC1608X95N | ~ | C19330 | Ferrite bead
FB9 | 1 | FerriteBead_Small |  | FerriteBead:ul_BLM21PG121SN1D | ~ |  | Ferrite bead, small symbol
IC1 | 1 | RT9193-15GB |  | SOT94P280X100-5N | https://www.richtek.com/assets/product_file/RT9193/DS9193-16.pdf |  | RICHTEK - RT9193-15GB - IC, LDO, FIXED, 1.5V, 0.3A, SOT-23-5
J1 | 1 | Conn_01x02_Pin |  | Connector_PinHeader_2.54mm:PinHeader_1x02_P2.54mm_Vertical | ~ |  | Generic connector, single row, 01x02, script generated
J2 | 1 | FH12-24S-0.5SH55 |  | CONN24X1_FH12-24S-0.5SH55_HIR | FH12-24S-0.5SH55 | C202112
J3 | 1 | Conn_01x02_Pin |  | Connector_PinHeader_2.54mm:PinHeader_1x02_P2.54mm_Vertical | ~ |  | Generic connector, single row, 01x02, script generated
J4 | 1 | Conn_01x04_Pin |  | Connector_PinHeader_2.54mm:PinHeader_1x04_P2.54mm_Vertical | ~ |  | Generic connector, single row, 01x04, script generated
J5 | 1 | Conn_01x02_Pin |  | Connector_PinHeader_2.54mm:PinHeader_1x02_P2.54mm_Vertical | ~ |  | Generic connector, single row, 01x02, script generated
J6 | 1 | USB_C_Receptacle_USB2.0_16P |  | Connector_USB:USB_C_Receptacle_HCTL_HC-TYPE-C-16P-01A | https://www.usb.org/sites/default/files/documents/usb_type-c.zip |  | USB 2.0-only 16P Type-C Receptacle connector
L1 | 1 | 2.2uH |  | Inductor_SMD:L_0402_1005Metric | ~ | C13595 | Inductor | C13595
L2 | 1 | DLW21SN900SQ2L |  | common_mode_choke:IND_DLW21S_0805_MUR-M | DLW21SN900SQ2L
MMICT1 | 1 | T3902 |  | MMIC:MIC_T3902 |  | C3171752
R1 | 1 | 100k |  | Resistor_SMD:R_0402_1005Metric | ~ | C17168 |  | C17168
R2 | 1 | 5.1K |  | Resistor_SMD:R_0402_1005Metric | ~ | C25905 |  | C25905
R3 | 1 | 100k |  | Resistor_SMD:R_0402_1005Metric | ~ | C17168 |  | C17168
R4 | 1 | 5.1K |  | Resistor_SMD:R_0402_1005Metric | ~ | C25905 |  | C25905
R6 | 1 | 10K |  | Resistor_SMD:R_0402_1005Metric | ~ | C25744 |  | C25744
R7 | 1 | 100k |  | Resistor_SMD:R_0402_1005Metric | ~ | C25744 |  | C25744
R8 | 1 | 20k |  | Resistor_SMD:R_0402_1005Metric | ~ | C25744 |  | C25744
R10 | 1 | 470R |  | Resistor_SMD:R_0402_1005Metric | ~ | C25117 |  | C25117
R12 | 1 | 470R |  | Resistor_SMD:R_0402_1005Metric | ~ | C25117 |  | C25117
R13 | 1 | 470R |  | Resistor_SMD:R_0402_1005Metric | ~ | C25117 |  | C25117
R14 | 1 | 22 |  | Resistor_SMD:R_0402_1005Metric | ~ | C25092 |  | C25744
R21 | 1 | 470R |  | Resistor_SMD:R_0402_1005Metric | ~ | C25117 |  | C25117
R23 | 1 | 10k |  | Resistor_SMD:R_0402_1005Metric | ~ | C25744 |  | C25744
R24 | 1 | 4.7k |  | Resistor_SMD:R_0402_1005Metric | ~ | C25900 |  | C25900
R25 | 1 | 4.7k |  | Resistor_SMD:R_0402_1005Metric | ~ | C25900 |  | C25900
R26 | 1 | 4.7k |  | Resistor_SMD:R_0402_1005Metric | ~ | C25900 |  | C25900
R27 | 1 | 10K |  | Resistor_SMD:R_0402_1005Metric | ~ | C25744 |  | C25744
Reset1 | 1 | Reset |  | Button_Switch_SMD:SW_Push_1P1T_XKB_TS-1187A | ~ | C318884 | Push button switch, generic, two pins | C318884
U1 | 1 | TLV70028_SOT23-5 |  | Package_TO_SOT_SMD:SOT-23-5 | http://www.ti.com/lit/ds/symlink/tlv700.pdf | C507266 | 200mA Low Dropout Voltage Regulator, Fixed Output 2.8V, SOT-23-5
U2 | 1 | TLV70018_SOT23-5 |  | Package_TO_SOT_SMD:SOT-23-5 | http://www.ti.com/lit/ds/symlink/tlv700.pdf | C79924 | 200mA Low Dropout Voltage Regulator, Fixed Output 1.8V, SOT-23-5
U3 | 1 | MAX98357A |  | Package_DFN_QFN:Max98753-ETE | https://www.analog.com/media/en/technical-documentation/data-sheets/MAX98357A-MAX98357B.pdf |  | Mono DAC with amplifier, I2S, PCM, TDM, 32-bit, 96khz, 3.2W, TQFP-16
U4 | 1 | TPS62A02ADRL |  | Package_TO_SOT_SMD:SOT-563 | https://www.ti.com/lit/gpn/tps62a02a | C5820994 | High Efficiency Synchronous Buck Converter with forced PWM, Adjustable Output 0.6V-5.5V, 2A, Power Good, Enable, SOT-563
U5 | 1 | ESP32-S3-WROOM-2 |  | RF_Module:ESP32-S3-WROOM-2 | https://www.espressif.com/sites/default/files/documentation/esp32-s3-wroom-2_datasheet_en.pdf |  | RF Module, 2.4 GHz, Wi-Fi, Bluetooth, BLE, ESP32--S3R8V

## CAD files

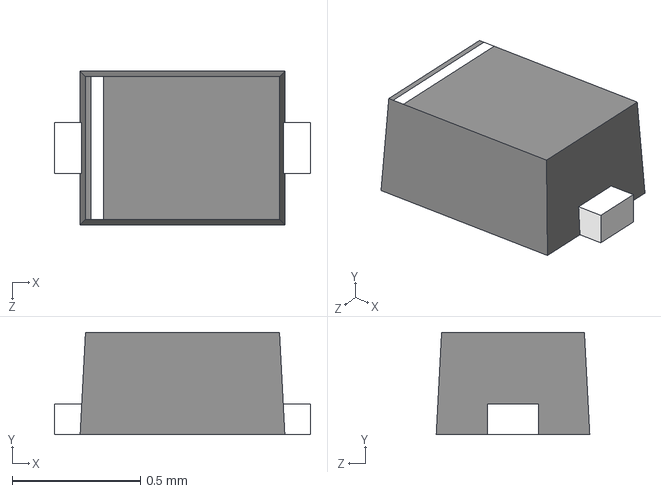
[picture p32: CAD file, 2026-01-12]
project_kicad9/ul_ESD9B3.3ST5G/ESD9B3.3ST5G.step
1 x 0.4 x 0.6 mm

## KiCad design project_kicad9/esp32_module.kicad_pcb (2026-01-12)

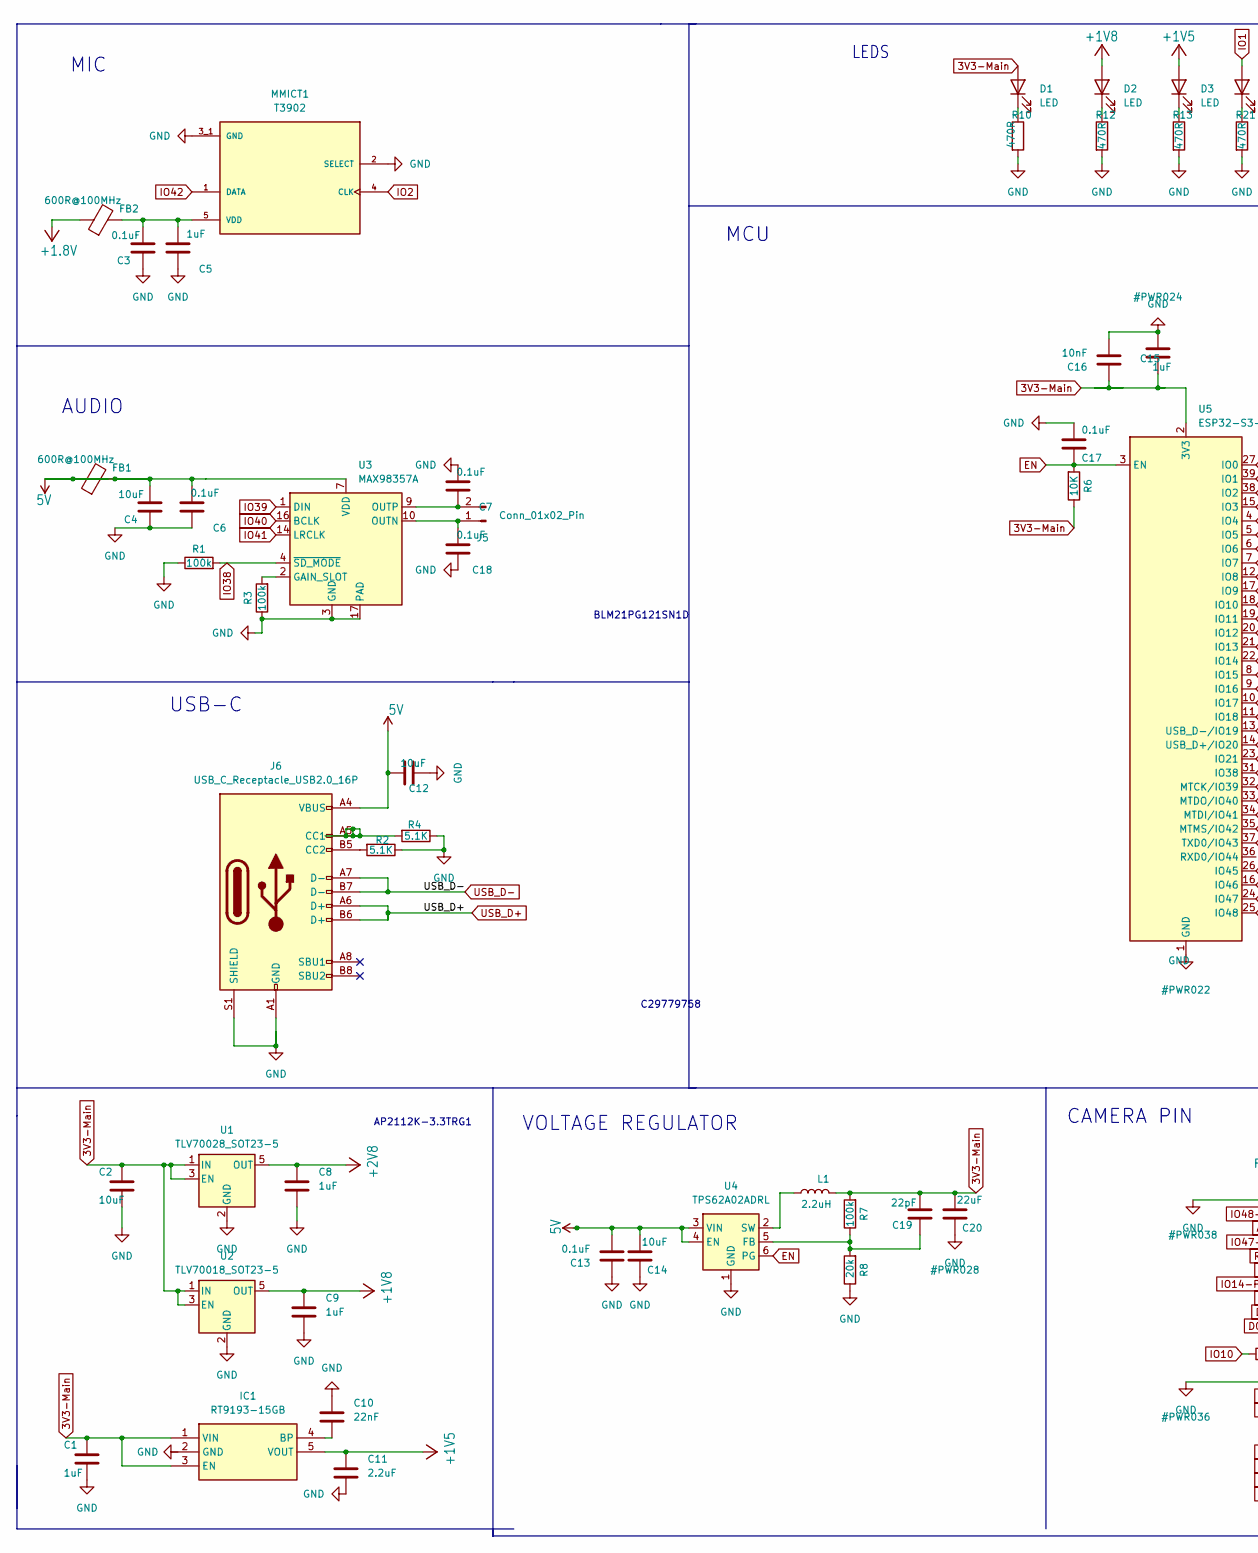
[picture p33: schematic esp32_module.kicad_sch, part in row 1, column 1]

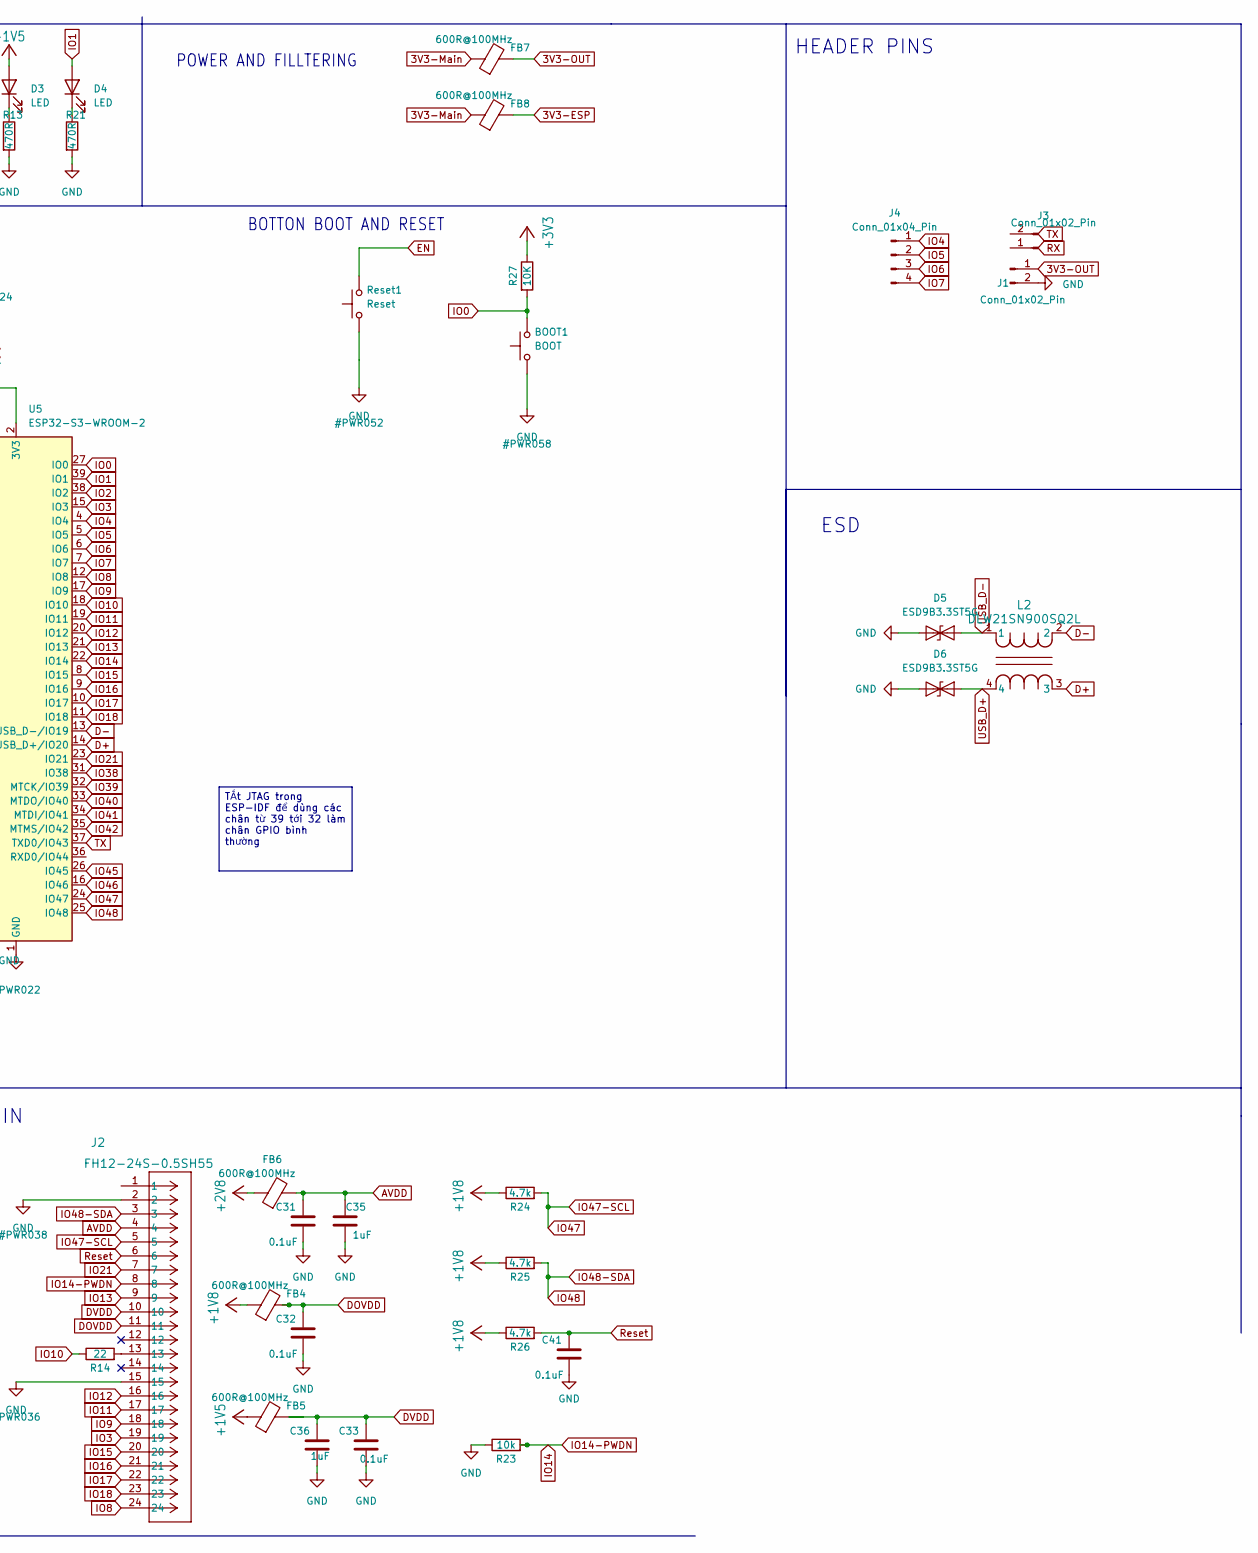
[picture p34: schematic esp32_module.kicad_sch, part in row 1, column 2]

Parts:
BOOT1: BOOT; SW_Push_1P1T_XKB_TS-1187A; MNF PART NUMBER C318884; LCSC C318884
C1, C8, C9, C15, C35, C36: 1uF; C_0402_1005Metric; MNF PART NUMBER C52923; LCSC C52923
C2, C12, C14: 10uF; C_0402_1005Metric; MNF PART NUMBER C15525; LCSC C15525
C3, C13, C17, C31, C32, C33, C41: 0.1uF; C_0402_1005Metric; MNF PART NUMBER C1525; LCSC C1525
C4: 10uF; C_0402_1005Metric; MNF PART NUMBER C1525; LCSC C1525
C5: 1uF; C_0402_1005Metric; MNF PART NUMBER C15525; LCSC C15525
C6, C7, C18: 0.1uF; C_0402_1005Metric; MNF PART NUMBER C15525; LCSC C15525
C10: 22nF; C_0402_1005Metric; MNF PART NUMBER C15525; LCSC C15525
C11: 2.2uF; C_0402_1005Metric; MNF PART NUMBER C107369; LCSC C107369
C16: 10nF; C_0402_1005Metric; MNF PART NUMBER C15195; LCSC C15195
C19: 22pF; C_0402_1005Metric; MNF PART NUMBER C70464; LCSC C70464
C20: 22uF; C_0402_1005Metric; MNF PART NUMBER C105226; LCSC C105226
D1, D2, D3, D4: LED; LED_0603_1608Metric; MNF PART NUMBER C2286; LCSC C2286
D5, D6: ESD9B3.3ST5G; D_SOD-923
FB1, FB2, FB4, FB5, FB6, FB7, FB8: 600R@100MHz; BEADC1608X95N; MNF PART NUMBER C19330
IC1: RT9193-15GB; SOT94P280X100-5N; Manufacturer_Part_Number RT9193-15GB; Mouser Part Number 835-RT9193-15GB
J1, J3, J5: Conn_01x02_Pin; PinHeader_1x02_P2.54mm_Vertical
J2: FH12-24S-0.5SH55; CONN24X1_FH12-24S-0.5SH55_HIR; MNF PART NUMBER C202112
J4: Conn_01x04_Pin; PinHeader_1x04_P2.54mm_Vertical
J6: USB_C_Receptacle_USB2.0_16P; USB_C_Receptacle_HCTL_HC-TYPE-C-16P-01A
L1: 2.2uH; L_0402_1005Metric; MNF PART NUMBER C13595; LCSC C13595
L2: DLW21SN900SQ2L; IND_DLW21S_0805_MUR-M
MMICT1: T3902; MIC_T3902; PARTREV 1.0
R1, R3: 100k; R_0402_1005Metric; MNF PART NUMBER C17168; LCSC C17168
R2, R4: 5.1K; R_0402_1005Metric; MNF PART NUMBER C25905; LCSC C25905
R6, R27: 10K; R_0402_1005Metric; MNF PART NUMBER C25744; LCSC C25744
R7: 100k; R_0402_1005Metric; MNF PART NUMBER C25744; LCSC C25744
R8: 20k; R_0402_1005Metric; MNF PART NUMBER C25744; LCSC C25744
R10, R12, R13, R21: 470R; R_0402_1005Metric; MNF PART NUMBER C25117; LCSC C25117
R14: 22; R_0402_1005Metric; MNF PART NUMBER C25092; LCSC C25744
R23: 10k; R_0402_1005Metric; MNF PART NUMBER C25744; LCSC C25744
R24, R25, R26: 4.7k; R_0402_1005Metric; MNF PART NUMBER C25900; LCSC C25900
Reset1: Reset; SW_Push_1P1T_XKB_TS-1187A; MNF PART NUMBER C318884; LCSC C318884
U1: TLV70028_SOT23-5; SOT-23-5; MNF PART NUMBER C507266
U2: TLV70018_SOT23-5; SOT-23-5; MNF PART NUMBER C79924
U3: MAX98357A; Max98753-ETE
U4: TPS62A02ADRL; SOT-563; MNF PART NUMBER C5820994
U5: ESP32-S3-WROOM-2

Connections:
3V3-Main: C1.1, C2.1, C15.1, C16.1, C19.2, C20.2, D1.2 (A), FB7.1, FB8.1, IC1.1 (VIN), IC1.3 (EN), L1.2, R6.1, R7.2, U1.1 (IN), U1.3 (EN), U2.1 (IN), U2.3 (EN), U5.2 (3V3)
3V3-OUT: FB7.2, J1.1
5V: C4.2, C6.2, C12.1, C13.2, C14.2, FB1.1, FB1.2, J6.A4 (VBUS), J6.A9 (VBUS), J6.B4 (VBUS), J6.B9 (VBUS), U3.7 (VDD), U3.8 (VDD), U4.3 (VIN), U4.4 (EN)
+1.8V: FB2.1
+1V5: C11.2, D3.2 (A), FB5.1, IC1.5 (VOUT)
+1V8: C9.2, D2.2 (A), FB4.1, R24.1, R25.1, R26.1, U2.5 (OUT)
+2V8: C8.1, FB6.1, U1.5 (OUT)
+3V3: R27.1
AVDD: C31.1, C35.1, FB6.2, J2.4
D+: L2.3, U5.14 (USB_D+/IO20)
D-: L2.2, U5.13 (USB_D-/IO19)
DOVDD: C32.1, FB4.2, J2.11
DVDD: C33.1, C36.1, FB5.2, J2.10
EN: C17.1, R6.2, Reset1.2, U4.6 (PG), U5.3 (EN)
GND: BOOT1.1, C1.2, C2.2, C3.1, C4.1, C5.1, C6.1, C7.2, C8.2, C9.1, C10.2, C11.1, C12.2, C13.1, C14.1, C15.2, C16.2, C17.2, C18.1, C20.1, C31.2, C32.2, C33.2, C35.2, C36.2, C41.2, D5.1 (A1), D6.1 (A1), J1.2, J2.2, J2.15, J6.A1 (GND), J6.A12 (GND), J6.B1 (GND), J6.B12 (GND), J6.S1 (SHIELD), MMICT1.2 (SELECT), MMICT1.3_1 (GND), MMICT1.3_2 (GND), R1.1, R2.1, R3.1, R4.1, R8.1, R10.2, R12.2, R13.2, R21.2, R23.1, Reset1.1, U1.2 (GND), U2.2 (GND), U3.3 (GND), U3.11 (GND), U3.15 (GND), U3.17 (PAD), U4.1 (GND), U5.1 (GND), U5.40 (GND), U5.41 (GND)
IO0: BOOT1.2, R27.2, U5.27 (IO0)
IO1: D4.2 (A), U5.39 (IO1)
IO2: MMICT1.4 (CLK), U5.38 (IO2)
IO3: J2.19, U5.15 (IO3)
IO4: J4.1, U5.4 (IO4)
IO5: J4.2, U5.5 (IO5)
IO6: J4.3, U5.6 (IO6)
IO7: J4.4, U5.7 (IO7)
IO8: J2.24, U5.12 (IO8)
IO9: J2.18, U5.17 (IO9)
IO10: R14.1, U5.18 (IO10)
IO11: J2.17, U5.19 (IO11)
IO12: J2.16, U5.20 (IO12)
IO13: J2.9, U5.21 (IO13)
IO14: J2.8, R23.2, U5.22 (IO14)
IO15: J2.20, U5.8 (IO15)
IO16: J2.21, U5.9 (IO16)
IO17: J2.22, U5.10 (IO17)
IO18: J2.23, U5.11 (IO18)
IO21: J2.7, U5.23 (IO21)
IO38: R1.2, U3.4 (~SD_MODE), U5.31 (IO38)
IO39: U3.1 (DIN), U5.32 (MTCK/IO39)
IO40: U3.16 (BCLK), U5.33 (MTDO/IO40)
IO41: U3.14 (LRCLK), U5.34 (MTDI/IO41)
IO42: MMICT1.1 (DATA), U5.35 (MTMS/IO42)
IO45: U5.26 (IO45)
IO46: U5.16 (IO46)
IO47: J2.5, R24.2, U5.24 (IO47)
IO48: J2.3, R25.2, U5.25 (IO48)
unnamed: D1.1 (K), R10.1
unnamed: D2.1 (K), R12.1
unnamed: D3.1 (K), R13.1
unnamed: D4.1 (K), R21.1
unnamed: C10.1, IC1.4 (BP)
unnamed: J2.13, R14.2
unnamed: C18.2, J5.1, U3.10 (OUTN)
unnamed: C7.1, J5.2, U3.9 (OUTP)
unnamed: J6.A5 (CC1), R4.2
unnamed: J6.B5 (CC2), R2.2
unnamed: C3.2, C5.2, FB2.2, MMICT1.5 (VDD)
unnamed: R3.2, U3.2 (GAIN_SLOT)
unnamed: C19.1, R7.1, R8.2, U4.5 (FB)
unnamed: L1.1, U4.2 (SW)
Reset: C41.1, J2.6, R26.2
TX: U5.37 (TXD0/IO43)
USB_D+: D6.2 (A2), J6.A6 (D+), J6.B6 (D+), L2.4
USB_D-: D5.2 (A2), J6.A7 (D-), J6.B7 (D-), L2.1

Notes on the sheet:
VOLTAGE REGULATOR
AP2112K-3.3TRG1
C29779758
LEDS
MCU
HEADER PINS
ESD
POWER AND FILLTERING
AUDIO
BOTTON BOOT AND RESET
MIC
CAMERA PIN
USB-C
BLM21PG121SN1D
TẮt JTAG trong ESP-IDF để dùng các chân từ 39 tới 32 làm chân GPIO bình thường

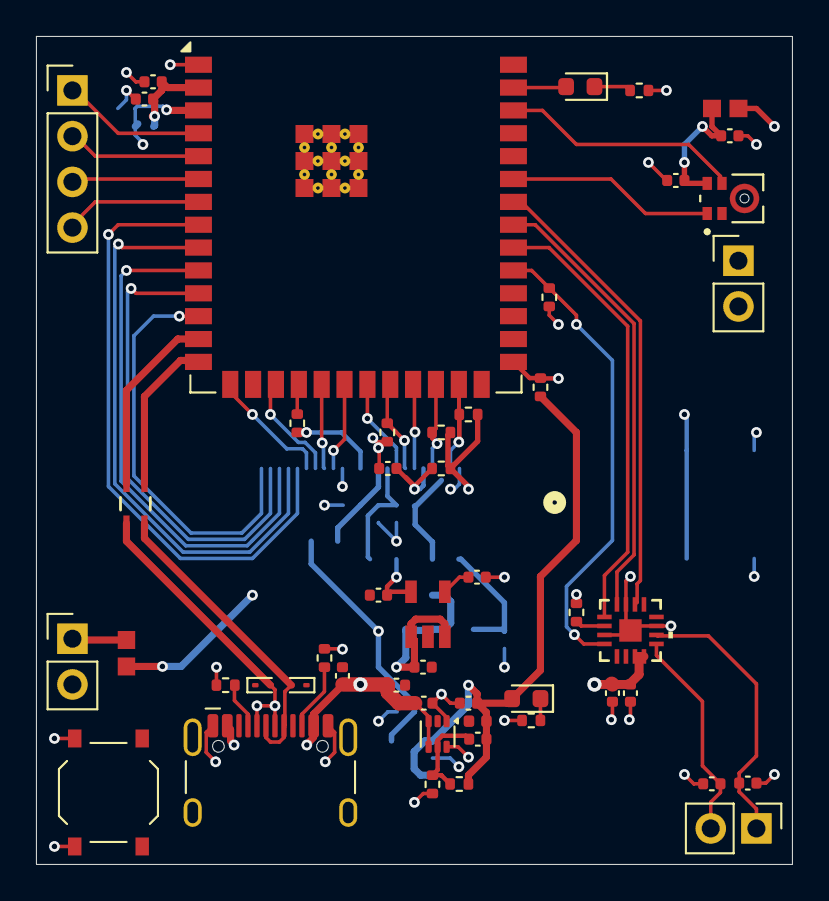
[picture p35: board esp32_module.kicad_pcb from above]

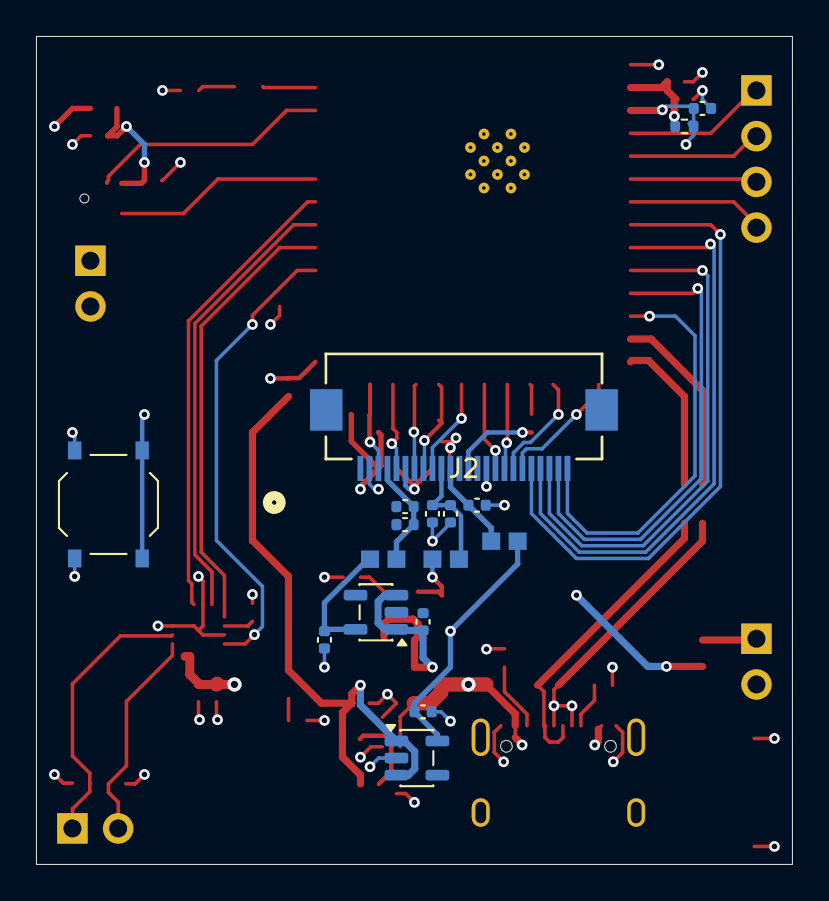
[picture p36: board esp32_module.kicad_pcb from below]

Board: 4 copper layers, 42.0 x 46.0 mm, 67 parts (17 on the bottom side), 55 nets.
